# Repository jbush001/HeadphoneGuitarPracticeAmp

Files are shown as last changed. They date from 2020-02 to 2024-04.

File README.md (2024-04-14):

I was looking for a headphone guitar amp with the following features:

- Integrated guitar plug: Doesn't require an extra cable or have a box
  flopping around.
- Rechargeable battery
- Flexible set of basic effects with decent quality: distortion, reverb,
  amp simulation, etc.
- Built-in metronome

Although there are commercially available headphone amps that support a few of
these, surprisingly, none supported all of them, so I decided to build my own.
The heart of this is an ARM microcontroller, which processes the audio signal
and applies digital effects. The hardware consists of a custom printed circuit
board in a 3D printed enclosure.

TBH, I kind of ran out of steam on this project. Pictures of the prototype I built
are in the Wiki: <https://github.com/jbush001/HeadphoneGuitarPracticeAmp/wiki/Prototype-Pictures>,
but I didn't end up bringing this up.



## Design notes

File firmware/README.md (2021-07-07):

Setting up software development environment:

* <https://www.amazon.com/Aideepen-ST-Link-Programming-Emulator-Downloader/dp/B01J7N3RE6>
* <https://www.amazon.com/DSD-TECH-SH-U09C2-Debugging-Programming/dp/B07TXVRQ7V>

## Macos

Install ARM toolchain:

    brew tap ArmMbed/homebrew-formulae
    brew install arm-none-eabi-gcc

## Linux

    sudo apt-get install gcc-arm-none-eabi binutils-arm-none-eabi

This requires at least version 1.6.1 of the st-link tools for STM32G4 support. This version
is not in Homebrew (at least), so they need to be built manually following instructions here:
<https://github.com/stlink-org/stlink/blob/develop/doc/compiling.md#macOS>

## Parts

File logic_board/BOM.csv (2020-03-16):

Manufacturer Part Number | Manufacturer | Digi-Key Part Number | Quantity | Unit Price | Description
C0805C106K8PACTU | KEMET | 399-4925-1-ND | 3 | 0.16000 | CAP CER 10UF 10V X5R 0805
 |  |  | 12 | 0.01800 | CAP CER 0.1UF 16V Y5V 0603
EEE-1VA220SP | Panasonic Electronic Components | PCE3952CT-ND | 2 | 0.35000 | CAP ALUM 22UF 20% 35V SMD
WP710A10LSRD | Kingbright | 754-1590-ND | 2 | 0.50000 | LED RED DIFFUSED T-1 T/H
LTST-C191TBKT | Lite-On Inc. | 160-1647-1-ND | 1 | 0.50000 | LED BLUE CLEAR CHIP SMD
SJ2-35953A-SMT-TR | CUI Devices | CP-SJ2-35953A-SMT-CT-ND | 1 | 1.41000 | AUDIO JACK, 3.5 MM, RT, 3 CONDUC
USB4085-GF-A | GCT | 2073-USB4085-GF-ATR-ND | 1 | 1.75000 | CONN RCPT USB2.0 TYPEC 16POS
B2B-PH-SM4-TB(LF)(SN) | JST Sales America Inc. | 455-1734-1-ND | 1 | 0.55000 | CONN HEADER SMD 2POS 2MM
,",",2" | 0.45000 | RES SMD 5.1K OHM 0.1% 1/16W 0603
PTN0805E5002BST1 | Vishay Thin Film | 764-1535-1-ND | 1 | 0.74000 | RES 50K OHM 0.1% 1/5W 0805
 |  |  | 1 | 0.10000 | RES SMD 100K OHM 1% 1/16W 0603
 |  |  | 2 | 0.10000 | RES SMD 47K OHM 1% 1/16W 0603
 |  |  | 1 | 0.10000 | RES SMD 1K OHM 1% 1/16W 0603
 |  |  | 1 | 0.10000 | RES SMD 2K OHM 1% 1/16W 0603
 |  |  | 3 | 0.43000 | RES SMD 1.5K OHM 0.1% 1/16W 0603
TL3315NF160Q | E-Switch | EG4621CT-ND | 4 | 0.18000 | SWITCH TACTILE SPST-NO 0.05A 15V
JS102011SAQN | C&K | 401-1999-1-ND | 1 | 0.56000 | SWITCH SLIDE SPDT 300MA 6V
STM32G473CET6 | STMicroelectronics | 497-STM32G473CET6-ND | 1 | 6.29000 | MAINSTREAM ARM CORTEX-M4 CORE WI
OPA340NA/3K | Texas Instruments | 296-26275-1-ND | 1 | 2.54000 | IC OPAMP GP 1 CIRCUIT SOT23-5
WM8731SEDS/V | Cirrus Logic Inc. | 598-2460-ND | 1 | 3.92000 | IC CODEC PORT INTERNET 28SSOP
SPX3819M5-L-3-3/TR | MaxLinear, Inc. | 1016-1873-1-ND | 1 | 0.51000 | IC REG LINEAR 3.3V 500MA SOT23-5
BQ24090DGQT | Texas Instruments | 296-25863-1-ND | 1 | 1.48000 | IC BATT CHRGR LI-ION 10MSOP
AWSCR-8.00CPLB-C30-T4 | Abracon LLC | 535-15118-1-ND | 1 | 0.50000 | CERAMIC RES 8.0000MHZ 30PF SMD
AWSCR-12.00CV-T | Abracon LLC | 535-10007-1-ND | 1 | 0.40000 | CERAMIC RES 12.0000MHZ 22PF SMD
2750 | Adafruit Industries LLC | 1528-1858-ND | 1 | 6.95000 | BATTERY LITHIUM 3.7V 350MAH
2P1216 | Switchcraft Inc. | SC2075-ND | 1 | 4.06000 | CONN PLUG MONO 6.35MM 2COND
 |  |  | 1 | 0.47000 | CAP CER 10UF 10V X5R 0603
EEE-1AA221XP | Panasonic Electronic Components | PCE3871CT-ND | 2 | 0.47000 | CAP ALUM 220UF 20% 10V SMD

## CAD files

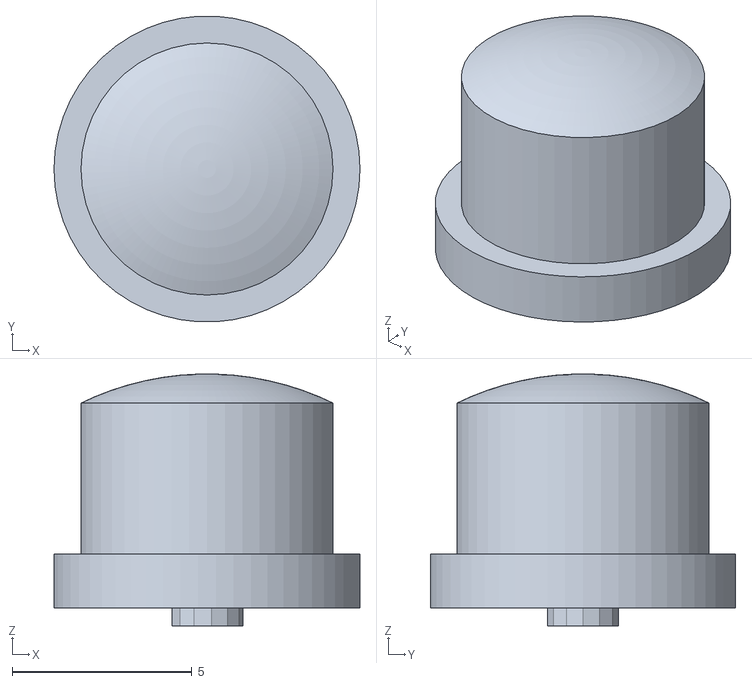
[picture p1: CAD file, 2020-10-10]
enclosure/button.stl
8.50 x 8.49 x 7.00

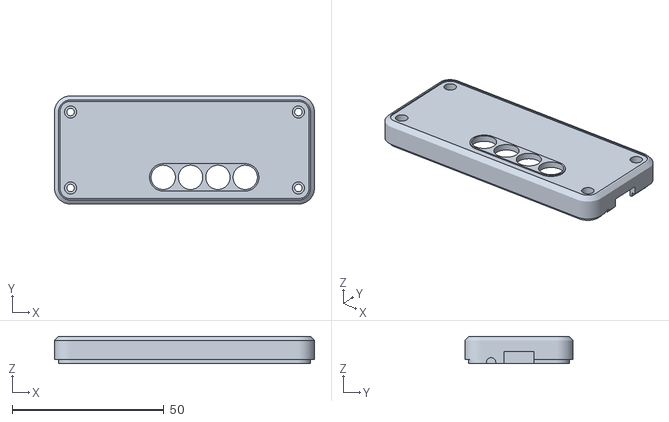
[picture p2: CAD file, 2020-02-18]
enclosure/top_enclosure.stl
85.6 x 35.6 x 9.00

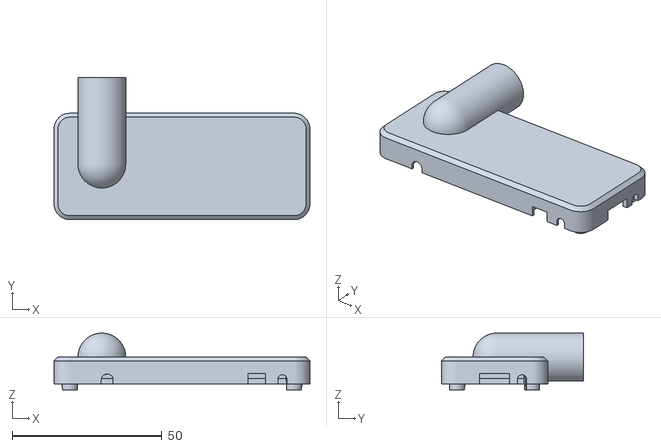
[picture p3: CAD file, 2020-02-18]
enclosure/bottom_enclosure.stl
85.6 x 47.6 x 19.0

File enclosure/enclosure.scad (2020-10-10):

//
// Print Settings (tested with Cura Slicer, Creality Ender 3)
//   Infill Density: 20%
//   Support Placement: Everywhere
//   Support Density: 20%
//   Layer Height: 0.2mm
// Both shells are printed with the open side pointed towards the print bed.
//

epsilon = 0.001; // Small offset used to avoid z-fighting
relief = 0.5; // Gap between interfacing parts to avoid sticking. Specific to printing process.
wall = 2; // Thickness of walls
pcb_thickness = 1.5; // Oshpark 4 layer board (actually 1.46)
$fs = 0.5;
$fa = 0.5;

pcb_xy_gap = 0.8; // horizontal gap between PCB and inside enclosure wall, on all sides.
enclosure_radius = 2.5 + wall + pcb_xy_gap;
pcb_width = 80;
pcb_height = 30;
pcb_screw_inset = 2.5; // center of screw from edge of PCB
pcb_z_offset = 3 + wall; // From top surface
lip_height = 1.8;
plug_cylinder_or = 16 / 2;
plug_cylinder_len = 37;
plug_opening_id = 10;
plug_x_offset = 8;
boss_od = pcb_screw_inset * 2;
top_boss_id = 2.5;   // For an M2.3 screw, should be larger
bottom_boss_id = 2.2;   // Also for M2.3 screw, we want it to self thread into this.
counterbore_id = 4.0; // Head of screw is 3.56mm
top_shell_depth = 9;
bottom_shell_depth = 9;
shell_width = pcb_width + pcb_xy_gap * 2 + wall * 2;
shell_height = pcb_height + pcb_xy_gap * 2 + wall * 2;
headphone_jack_radius = 3.175 / 2;
led_radius = 2.5; // 5mm

module shell(width, height, depth, radius) {
    hull() {
        chamfer = radius / 4;

        x1 = radius;
        y1 = radius;
        x2 = width - radius;
        y2 = height - radius;

        translate([x1, y1, 0]) cylinder(r=radius, h=depth - chamfer);
        translate([x2, y1, 0]) cylinder(r=radius, h=depth - chamfer);
        translate([x1, y2, 0]) cylinder(r=radius, h=depth - chamfer);
        translate([x2, y2, 0]) cylinder(r=radius, h=depth - chamfer);

        translate([x1, y1, 0]) cylinder(r=radius - chamfer, h=depth);
        translate([x2, y1, 0]) cylinder(r=radius - chamfer, h=depth);
        translate([x1, y2, 0]) cylinder(r=radius - chamfer, h=depth);
        translate([x2, y2, 0]) cylinder(r=radius - chamfer, h=depth);
    }
}

// Radius all vertical surfaces, but not top and bottom
module rounded_rect(width, height, depth, radius) {
    hull() {
        translate([radius, radius, 0]) cylinder(r=radius, h=depth);
        translate([width - radius, radius, 0]) cylinder(r=radius, h=depth);
        translate([width - radius, height - radius, 0]) cylinder(r=radius, h=depth);
        translate([radius, height - radius, 0]) cylinder(r=radius, h=depth);
    }
}

// Cylinder with a ball end
module rounded_cylinder(height, radius) {
    translate([radius, radius, 0]) cylinder(h=height - radius, r=radius);
    translate([radius, radius, height - radius]) sphere(radius);
}

module bottom_shell() {
    difference() {
        union() {
            // Outer shell
            translate([0, 0, 0]) shell(shell_width, shell_height, bottom_shell_depth, enclosure_radius);

            // Plug holder
            rotate([90, 0, 0]) translate([plug_x_offset, bottom_shell_depth - plug_cylinder_or, -shell_height - 12]) {
                rounded_cylinder(plug_cylinder_len, plug_cylinder_or);
            }
        }

        union() {
            translate([0, 0, -20]) cube([shell_width, shell_height, 20]);
            translate([wall, wall, -wall]) shell(shell_width - wall * 2, shell_height - wall * 2,
                bottom_shell_depth, enclosure_radius - wall);

            // lip (outer)
            translate([wall / 2 - relief / 2, wall / 2 - relief / 2, -epsilon])
                rounded_rect(shell_width - (wall / 2) * 2 - relief, shell_height - (wall / 2 / 2) * 2 - relief,
                    lip_height, enclosure_radius - (wall - wall / 2 - relief));

            // Inside of plug holder
            rotate([90, 0, 0]) translate([plug_x_offset, bottom_shell_depth - plug_cylinder_or, -shell_height - 12 + wall]) {
                translate([wall, wall, -epsilon]) rounded_cylinder(plug_cylinder_len - wall * 2 + epsilon, plug_cylinder_or - wall);
                translate([plug_cylinder_or, plug_cylinder_or, -3]) cylinder(d=plug_opening_id, h=6); // Opening
            }
        }
    }

}

module top_shell() {
    INSET = wall / 2;

    difference() {
        union() {
            difference() {
                shell(shell_width, shell_height, top_shell_depth, enclosure_radius);
                translate([-epsilon, -epsilon, -10]) cube([shell_width + epsilon * 2, shell_height + epsilon * 2,
                    10 + lip_height - relief]);
            }

            // Lip (inner)
            translate([wall / 2 + relief / 2, INSET + relief / 2, -epsilon]) rounded_rect(
                shell_width - wall - relief,
                shell_height - wall - relief,
                INSET * 2, enclosure_radius - (wall - INSET));
        }

        // Cavity
        translate([wall, wall, -wall]) shell(shell_width - wall * 2, shell_height - wall * 2,
            top_shell_depth, enclosure_radius - wall);
    }
}

module make_side_hole(diameter, isbottom) {
    cylinder(d=diameter, h=4);
    if (isbottom)
        translate([-diameter / 2, 0, 0]) cube([diameter, diameter + 1, 4]);
    else
        translate([-diameter / 2, -diameter, 0]) cube([diameter, diameter, 4]);
}


// This is from the origin of the top surface of the PCB, with positive
// extending away from the bottom.
// The isbottom flag cuts the lip away in the correct direction.
module openings(isbottom) {
    // USB port. This extends 3.2mm from the PCB surface it is soldered to and is
    // about 9.18mm wide.
    usb_port_width = 10;
    usb_port_height = 4;
    translate([pcb_width - 1, (pcb_height - usb_port_width) / 2, 0])
        cube([4, usb_port_width, usb_port_height + pcb_thickness]);

    // Charging LED
    translate([pcb_width - 1, 24.19, pcb_thickness + led_od / 2 + 0.5]) rotate([90, 180, 90])
        make_side_hole(led_od, isbottom);

    // Power LED
    led_od = 3.1;
    translate([73.56836, -3, pcb_thickness + led_od / 2 + 0.5]) rotate([-90, 0, 0]) make_side_hole(led_od,  isbottom);

    // Power switch
    // Center x is 70mm from origin
    // 2mm travel, switch is 1.5mm wide.
    translate([65 - 3, -3, 0]) cube([6, 5, 4 + pcb_thickness]);

    // Audio jack
    jack_id = 4;
    translate([15, -3, pcb_thickness + 1.85]) rotate([-90, 0, 0]) make_side_hole(jack_id, isbottom);

    // Front buttons
    for (i = [0:3])
        translate([33 + i * 9, 24, 0]) rotate([0, -180, 0]) cylinder(d=7 + relief * 2, h=7);
}

module bottom_enclosure() {
    boss_length = top_shell_depth + bottom_shell_depth - pcb_z_offset - pcb_thickness - relief; // offset from bottom surface
    boss_top = bottom_shell_depth - boss_length;
    xy1 = pcb_screw_inset + wall + pcb_xy_gap;
    x2 = xy1 + pcb_width - pcb_screw_inset * 2;
    y2 = xy1 + pcb_height - pcb_screw_inset * 2;

    difference() {
        union() {
            bottom_shell();

            translate([xy1, xy1, boss_top]) cylinder(d1=boss_od, d2=boss_od + 1, h=boss_length);
            translate([x2, xy1, boss_top]) cylinder(d1=boss_od, d2=boss_od + 1, h=boss_length);
            translate([xy1, y2, boss_top]) cylinder(d1=boss_od, d2=boss_od + 1, h=boss_length);
            translate([x2, y2, boss_top]) cylinder(d1=boss_od, d2=boss_od + 1, h=boss_length);
        }

        union() {
            // Screw holes to attach to top.
            translate([xy1, xy1, boss_top - epsilon]) cylinder(d=bottom_boss_id, h=boss_length - wall);
            translate([x2, xy1, boss_top - epsilon]) cylinder(d=bottom_boss_id, h=boss_length - wall);
            translate([xy1, y2, boss_top - epsilon]) cylinder(d=bottom_boss_id, h=boss_length - wall);
            translate([x2, y2, boss_top - epsilon]) cylinder(d=bottom_boss_id, h=boss_length - wall);
            translate([wall + pcb_xy_gap, wall + pcb_xy_gap, boss_top]) openings(true);
        }
    }
}

module top_enclosure() {
    pcb_boss_bottom = top_shell_depth - pcb_z_offset;

    xy1 = pcb_screw_inset + wall + pcb_xy_gap;
    x2 = xy1 + pcb_width - pcb_screw_inset * 2;
    y2 = xy1 + pcb_height - pcb_screw_inset * 2;

    difference() {
        union() {
            top_shell();

            // Bosses to attach to bottom
            translate([xy1, xy1, pcb_boss_bottom]) cylinder(d1=boss_od, d2=boss_od + 1, h=pcb_z_offset);
            translate([x2, xy1, pcb_boss_bottom]) cylinder(d1=boss_od, d2=boss_od + 1, h=pcb_z_offset);
            translate([xy1, y2, pcb_boss_bottom]) cylinder(d1=boss_od, d2=boss_od + 1, h=pcb_z_offset);
            translate([x2, y2, pcb_boss_bottom]) cylinder(d1=boss_od, d2=boss_od + 1, h=pcb_z_offset);
        }
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

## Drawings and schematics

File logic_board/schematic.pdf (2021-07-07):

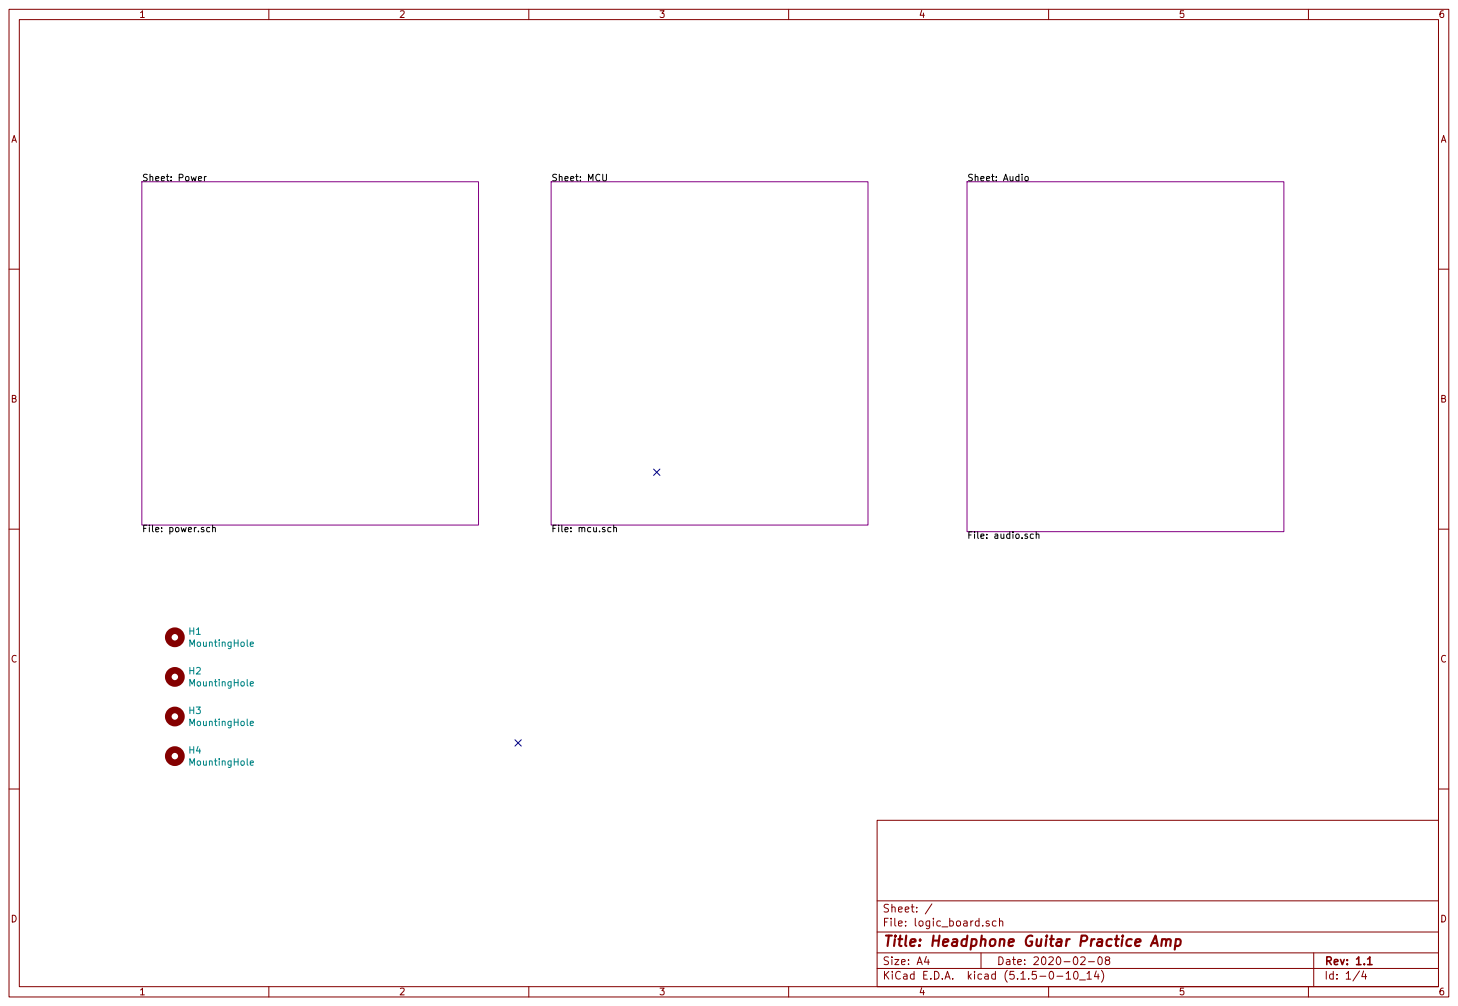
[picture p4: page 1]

File: logic_board.sch Sheet: /
Id: 1/4 Title: Headphone Guitar Practice Amp

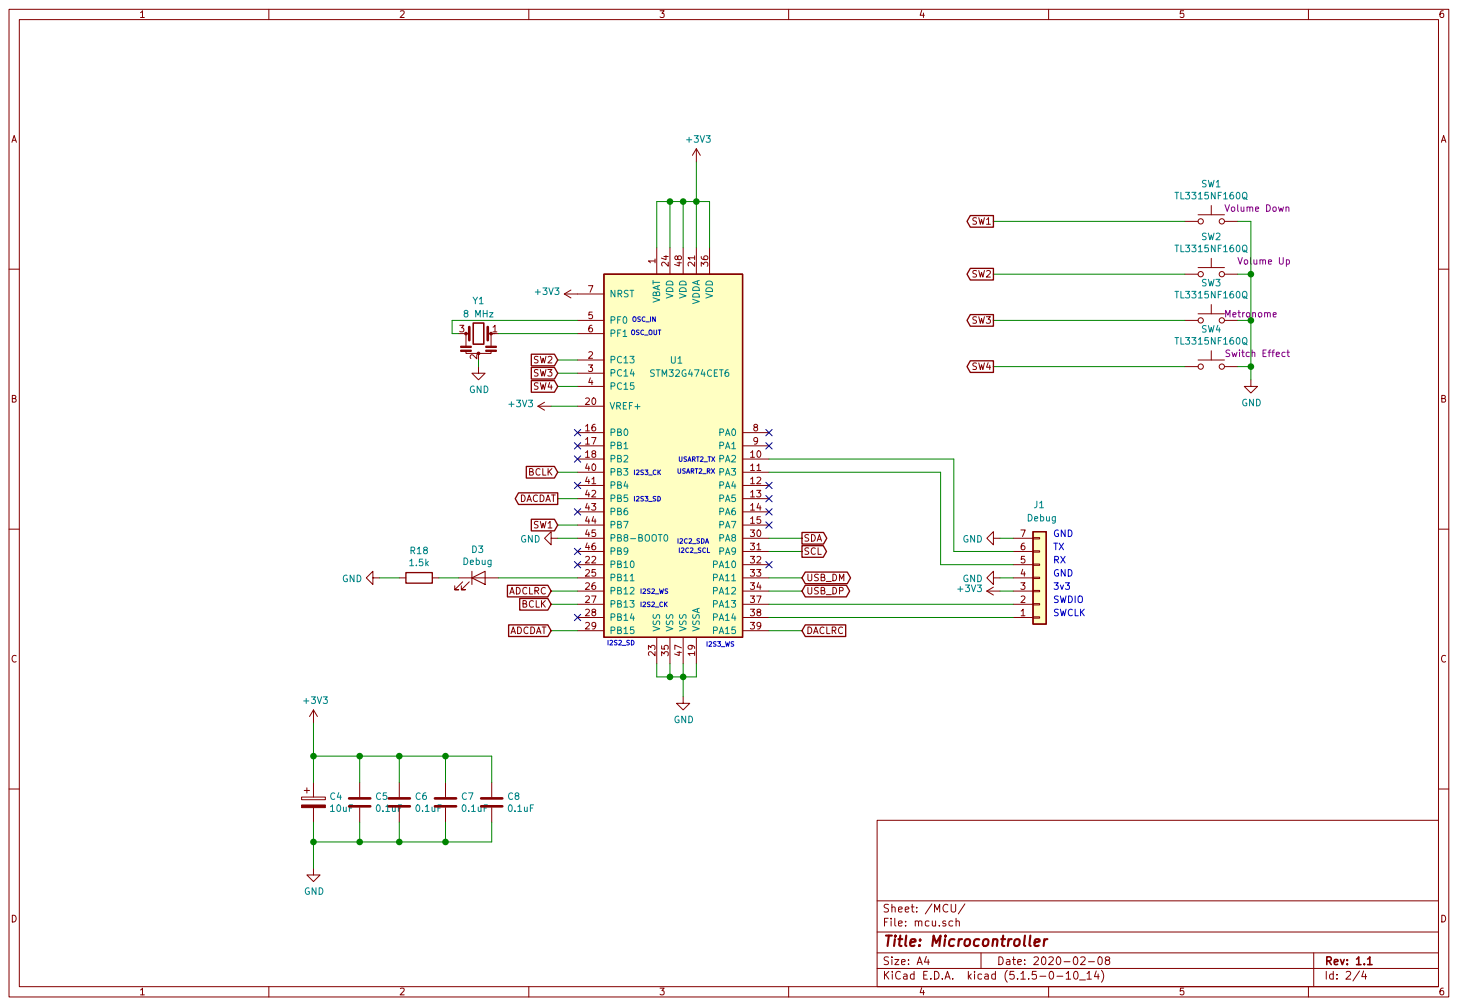
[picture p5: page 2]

1 PA2 10 PA3 11 PA4 12 PA5 13 PA6 14 PA7 15 PB0 16 PB1 17 PB2 18 VSSA 19 PC13 2 VREF+ 20 VDDA 21 PB10 22 VSS 23 VDD 24 PB11 25 PB12 26 PB13 27 PB14 28 PB15 29 PC14 3 PA8 30 PA9 31 PA10 32 PA11 33 PA12 34 VSS 35 VDD 36 PA13 37 PA14 38 PA15 39 PC15 4 PB3 40 PB4 41 PB5 42 PB6 43 PB7 44 PB8-BOOT0 45 PB9 46 VSS 47 VDD 48 PF0 5 PF1 6 NRST 7 PA0 8 PA1 9 U1 STM32G474CET6 C4

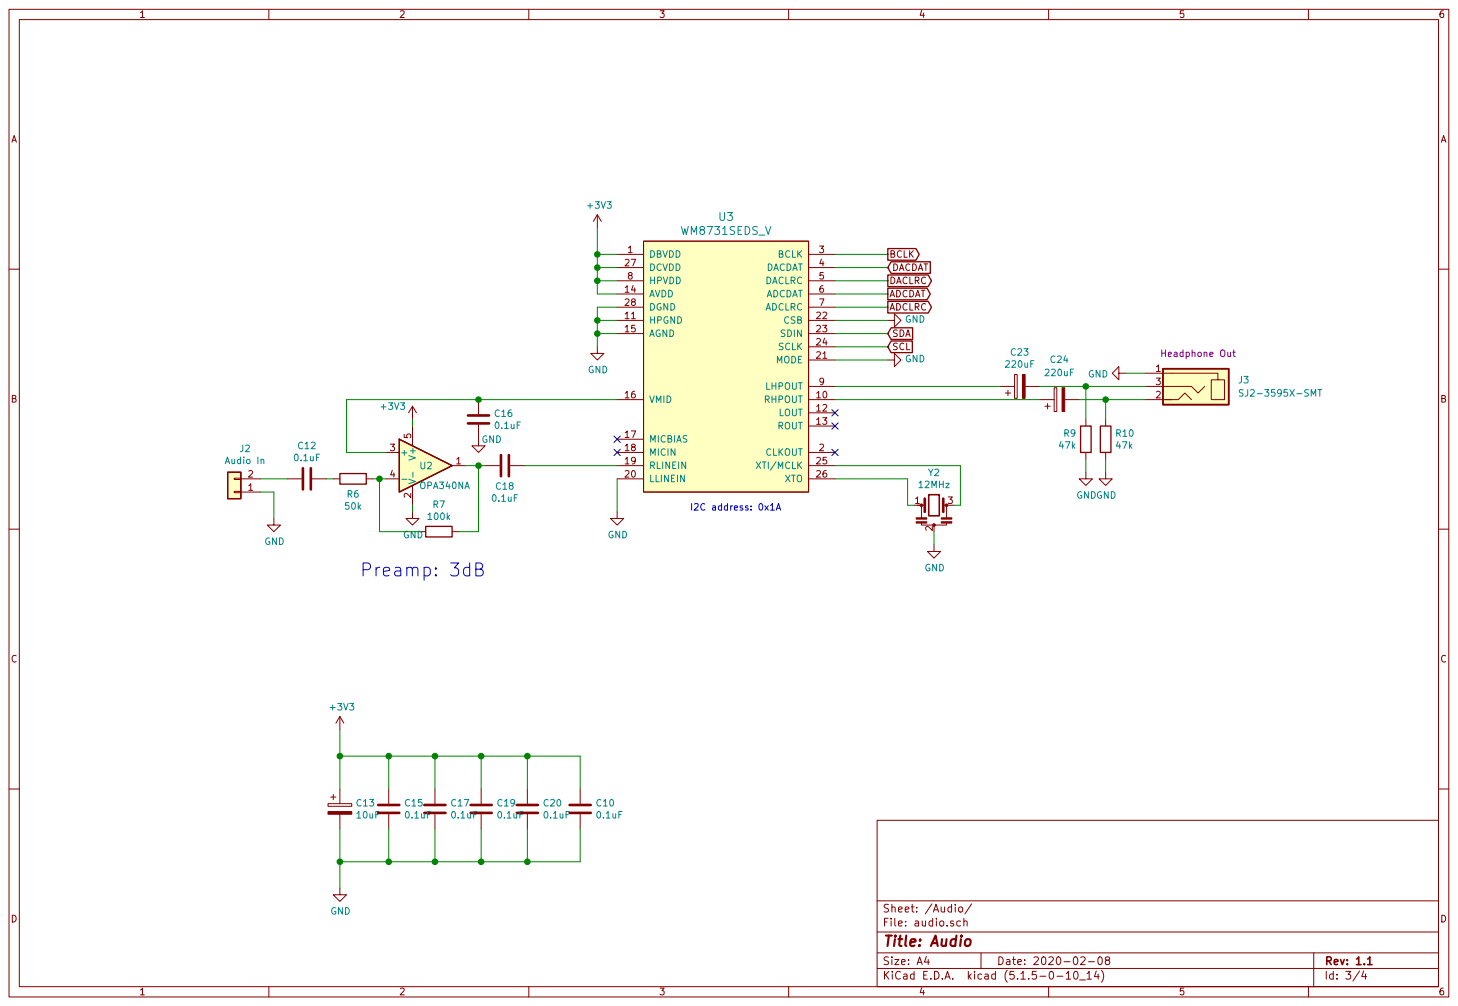
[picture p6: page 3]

File: audio.sch Sheet: /Audio/
Id: 3/4 Title: Audio

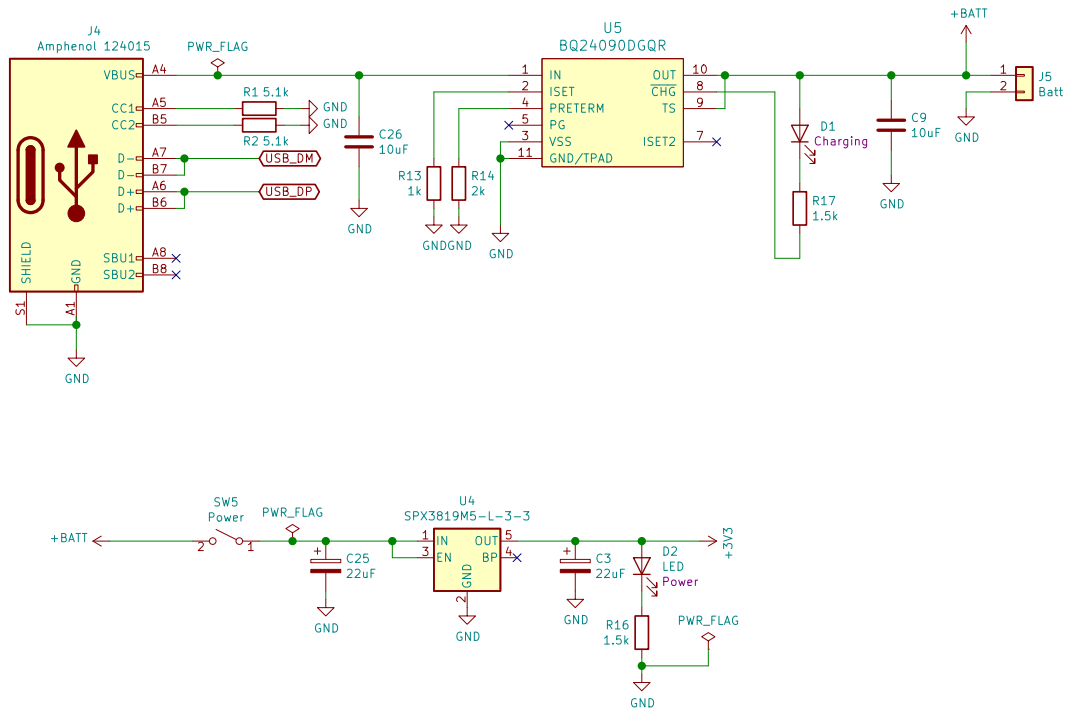
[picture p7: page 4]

2 EN 3 BP 4 OUT 5 U4 PWR_FLAG SPX3819M5-L-3-3 GND GND

File: power.sch Sheet: /Power/
Id: 4/4 Title: Power

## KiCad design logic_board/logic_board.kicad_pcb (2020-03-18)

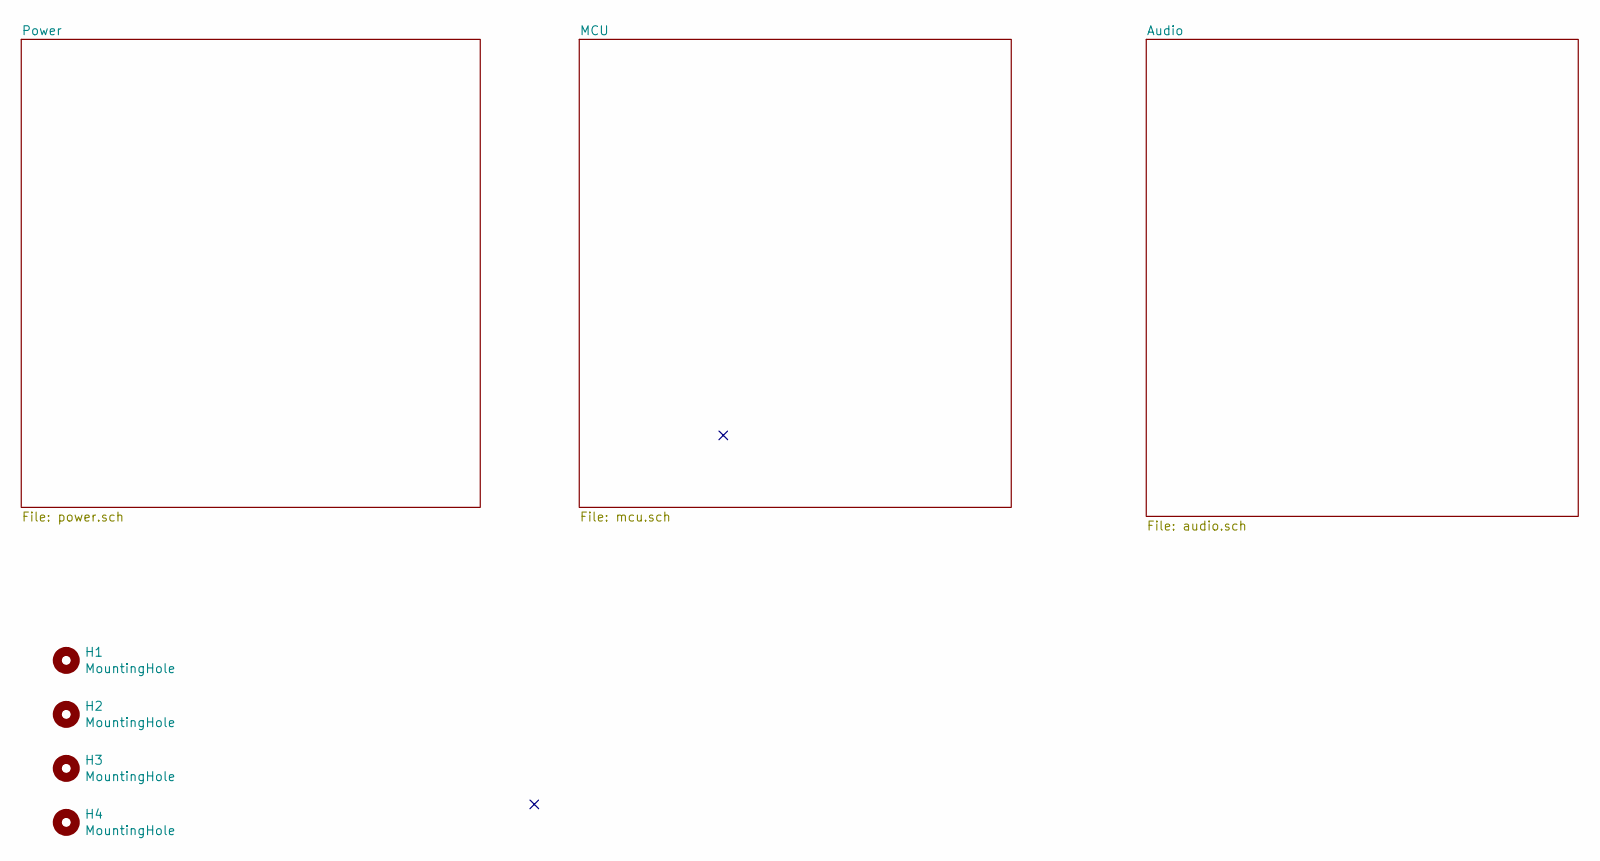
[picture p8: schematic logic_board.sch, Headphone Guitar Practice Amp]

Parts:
H1, H2, H3, H4: MountingHole; MountingHole_2.5mm

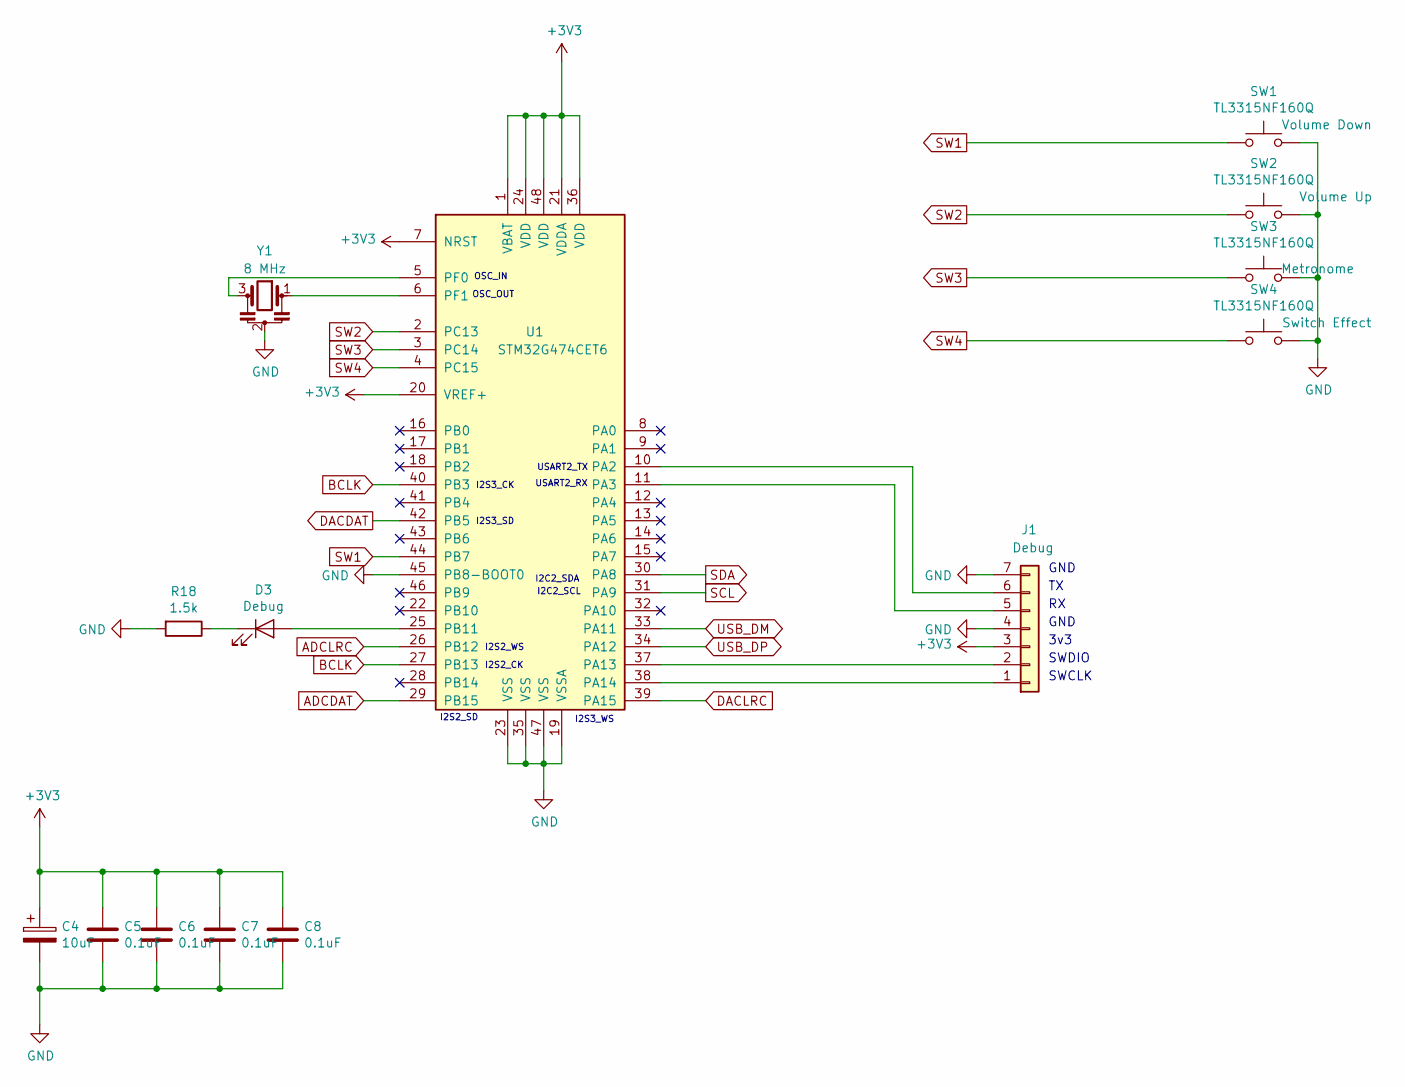
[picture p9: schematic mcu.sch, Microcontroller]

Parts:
C4: 10uF; C_0805_2012Metric_Pad1.15x1.40mm_HandSolder
C5, C6, C7, C8: 0.1uF; C_0603_1608Metric_Pad1.05x0.95mm_HandSolder
D3: Debug; LED_0603_1608Metric_Pad1.05x0.95mm_HandSolder
J1: Debug; PinHeader_1x07_P2.54mm_Vertical
R18: 1.5k; R_0603_1608Metric_Pad1.05x0.95mm_HandSolder
SW1, SW2, SW3, SW4: TL3315NF160Q; TL3315NF160Q_Tactile_Switch
U1: STM32G474CET6; LQFP-48_7x7mm_P0.5mm
Y1: 8 MHz; AWSCR-8.00CPLB-C30-T4

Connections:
+3V3: C4.1, C5.1, C6.1, C7.1, C8.1, J1.3, U1.1 (VBAT), U1.7 (NRST), U1.20 (VREF+), U1.21 (VDDA), U1.24 (VDD), U1.36 (VDD), U1.48 (VDD); also elsewhere on the board
ADCDAT: U1.29 (PB15); also elsewhere on the board
ADCLRC: U1.26 (PB12); also elsewhere on the board
BCLK: U1.27 (PB13), U1.40 (PB3); also elsewhere on the board
DACDAT: U1.42 (PB5); also elsewhere on the board
DACLRC: U1.39 (PA15); also elsewhere on the board
GND: C4.2, C5.2, C6.2, C7.2, C8.2, J1.4, J1.7, R18.2, SW1.2, SW2.2, SW3.2, SW4.2, U1.19 (VSSA), U1.23 (VSS), U1.35 (VSS), U1.45 (PB8-BOOT0), U1.47 (VSS), Y1.2; also elsewhere on the board
unnamed: D3.1 (K), R18.1
unnamed: D3.2 (A), U1.25 (PB11)
unnamed: J1.1, U1.38 (PA14)
unnamed: J1.2, U1.37 (PA13)
unnamed: J1.5, U1.11 (PA3)
unnamed: J1.6, U1.10 (PA2)
unnamed: U1.5 (PF0), Y1.3
unnamed: U1.6 (PF1), Y1.1
SCL: U1.31 (PA9); also elsewhere on the board
SDA: U1.30 (PA8); also elsewhere on the board
SW1: SW1.1, U1.44 (PB7)
SW2: SW2.1, U1.2 (PC13)
SW3: SW3.1, U1.3 (PC14)
SW4: SW4.1, U1.4 (PC15)
USB_DM: U1.33 (PA11); also elsewhere on the board
USB_DP: U1.34 (PA12); also elsewhere on the board

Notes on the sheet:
SWDIO
SWCLK
3v3
GND
I2S3_WS
I2S2_SD
I2S2_CK
I2S2_WS
I2S3_SD
I2S3_CK
USART2_TX
USART2_RX
I2C2_SDA
I2C2_SCL
OSC_IN
OSC_OUT

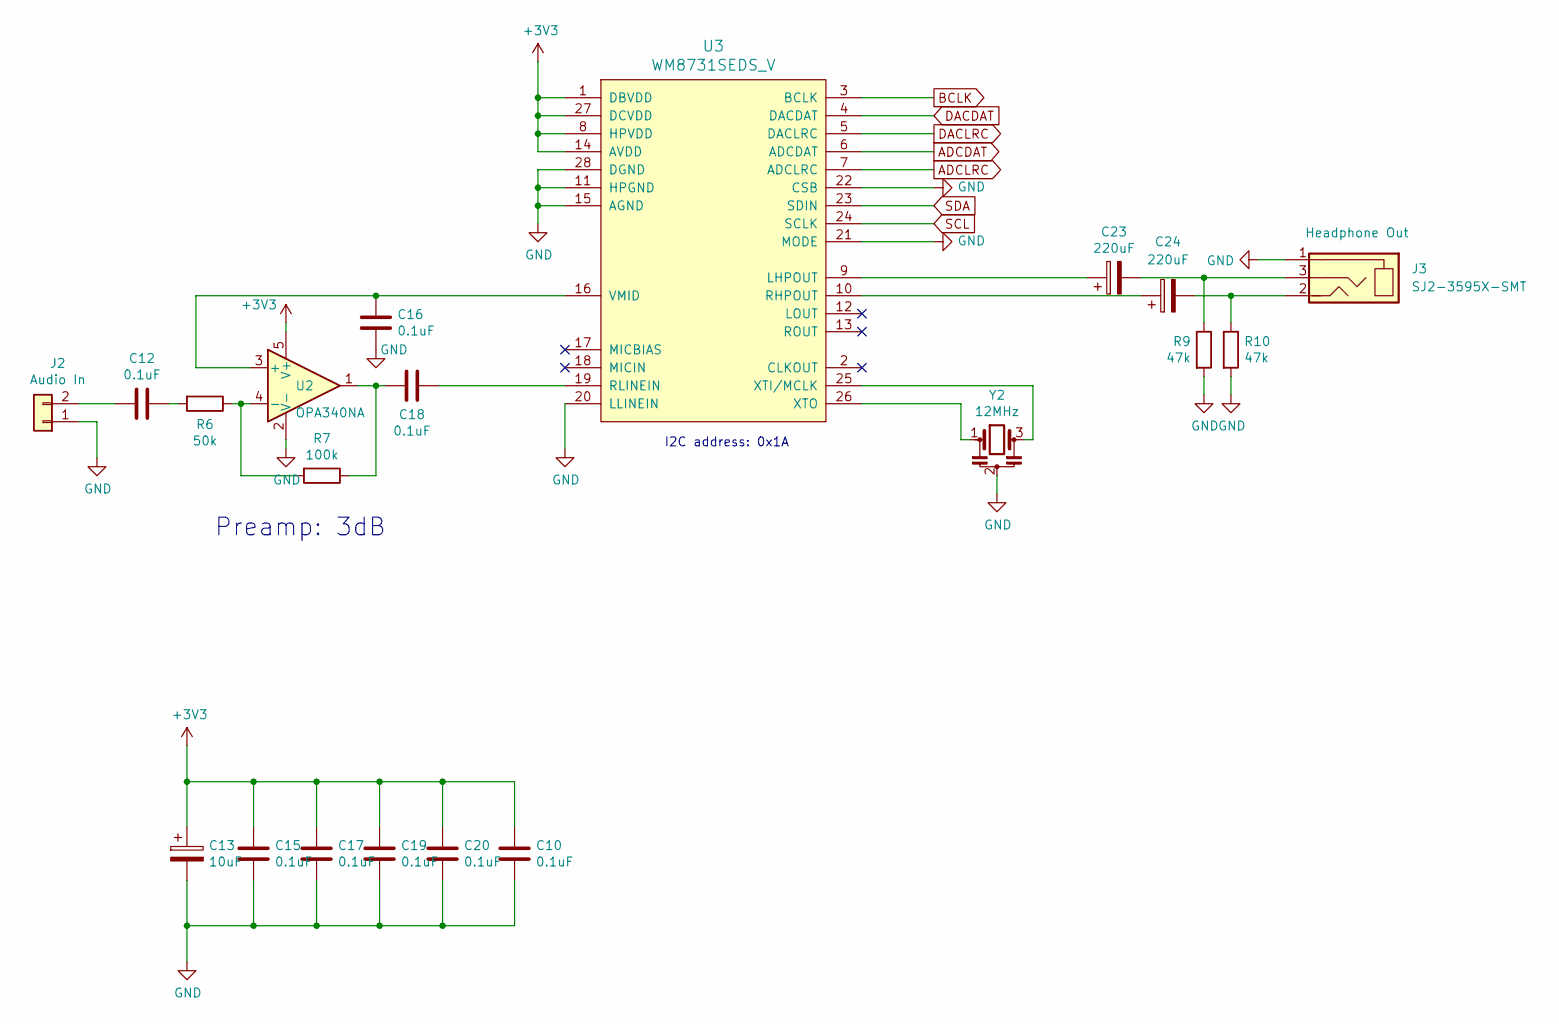
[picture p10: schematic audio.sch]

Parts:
C10, C12, C15, C16, C17, C18, C19, C20: 0.1uF; C_0603_1608Metric_Pad1.05x0.95mm_HandSolder
C13: 10uF; C_0805_2012Metric_Pad1.15x1.40mm_HandSolder
C23, C24: 220uF; C_1206_3216Metric_Pad1.42x1.75mm_HandSolder
J2: Audio In; Solder Pads 2x1
J3: SJ2-3595X-SMT; SJ2-3595X-SMT_3.5MM_JACK
R6: 50k; R_0805_2012Metric_Pad1.15x1.40mm_HandSolder
R7: 100k; R_0603_1608Metric_Pad1.05x0.95mm_HandSolder
R9, R10: 47k; R_0603_1608Metric_Pad1.05x0.95mm_HandSolder
U2: OPA340NA; SOT-23-5_HandSoldering
U3: WM8731SEDS_V; SSOP-28_5.3x10.2mm_P0.65mm
Y2: 12MHz; AWSCR-12.00CV-T

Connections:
+3V3: C10.1, C13.1, C15.1, C17.1, C19.1, C20.1, U2.5 (V+), U3.1 (DBVDD), U3.8 (HPVDD), U3.14 (AVDD), U3.27 (DCVDD); also elsewhere on the board
ADCDAT: U3.6 (ADCDAT); also elsewhere on the board
ADCLRC: U3.7 (ADCLRC); also elsewhere on the board
BCLK: U3.3 (BCLK); also elsewhere on the board
DACDAT: U3.4 (DACDAT); also elsewhere on the board
DACLRC: U3.5 (DACLRC); also elsewhere on the board
GND: C10.2, C13.2, C15.2, C16.2, C17.2, C19.2, C20.2, J2.1, J3.1, R9.2, R10.2, U2.2 (V-), U3.11 (HPGND), U3.15 (AGND), U3.20 (LLINEIN), U3.21 (MODE), U3.22 (CSB), U3.28 (DGND), Y2.2; also elsewhere on the board
unnamed: C12.1, R6.2
unnamed: C12.2, J2.2
unnamed: C16.1, U2.3 (+), U3.16 (VMID)
unnamed: C18.1, R7.1, U2.1
unnamed: C18.2, U3.19 (RLINEIN)
unnamed: C23.1, U3.9 (LHPOUT)
unnamed: C23.2, J3.3, R9.1
unnamed: C24.1, U3.10 (RHPOUT)
unnamed: C24.2, J3.2, R10.1
unnamed: R6.1, R7.2, U2.4 (-)
unnamed: U3.25 (XTI/MCLK), Y2.3
unnamed: U3.26 (XTO), Y2.1
SCL: U3.24 (SCLK); also elsewhere on the board
SDA: U3.23 (SDIN); also elsewhere on the board

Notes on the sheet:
Preamp: 3dB
I2C address: 0x1A

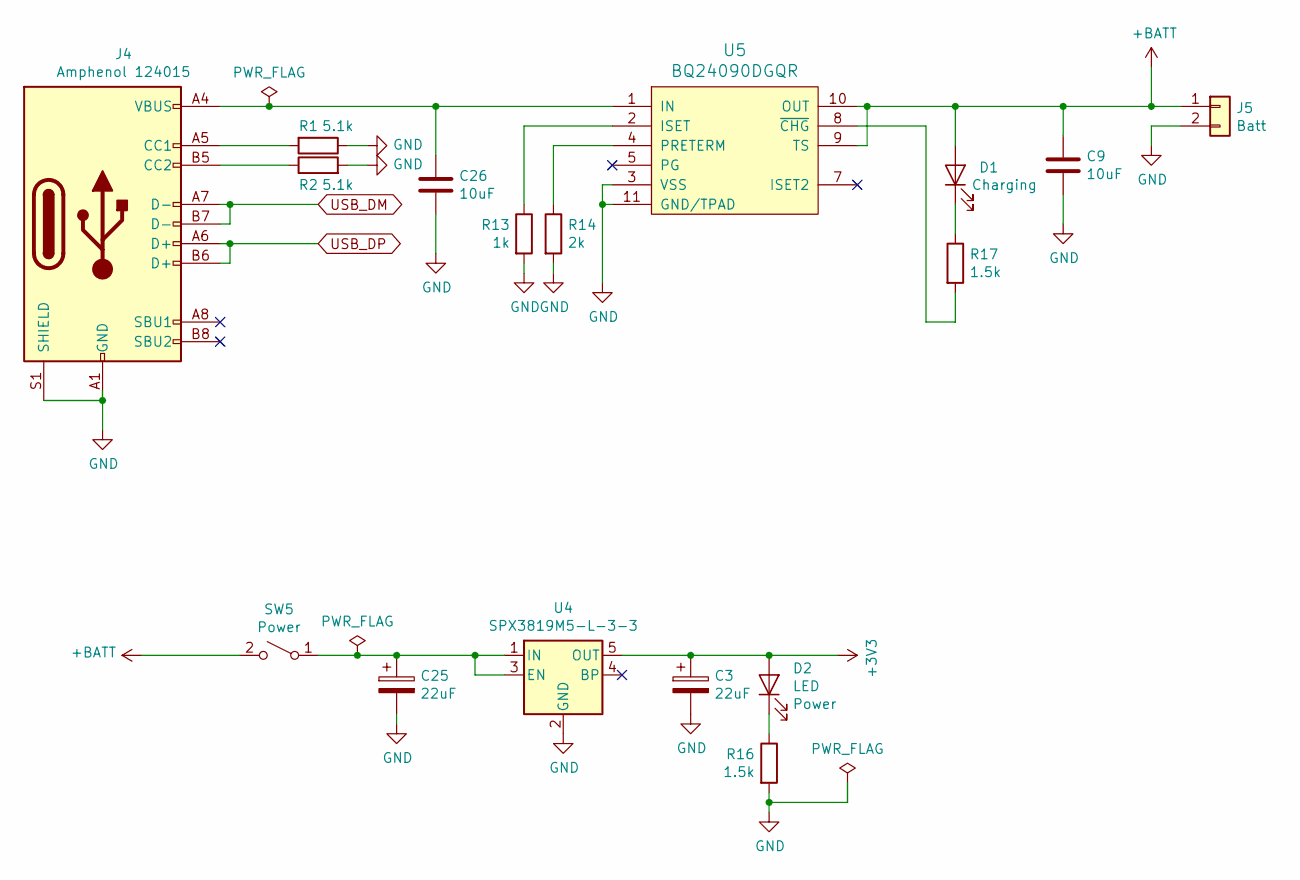
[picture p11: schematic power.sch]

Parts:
C3, C25: 22uF; CP_Elec_6.3x4.5
C9: 10uF; C_0603_1608Metric_Pad1.05x0.95mm_HandSolder
C26: 10uF; C_0805_2012Metric_Pad1.15x1.40mm_HandSolder
D1, D2: LED; LED_D3.0mm_Horizontal_O1.27mm_Z2.0mm
J4: Amphenol 124015; USB_C_Receptacle_GCT_USB4085
J5: Batt; JST PH HEADER SMD 2POS 2MM
R1, R2: 5.1k; R_0603_1608Metric_Pad1.05x0.95mm_HandSolder
R13: 1k; R_0603_1608Metric_Pad1.05x0.95mm_HandSolder
R14: 2k; R_0603_1608Metric_Pad1.05x0.95mm_HandSolder
R16, R17: 1.5k; R_0603_1608Metric_Pad1.05x0.95mm_HandSolder
SW5: Power; JS102011SAQN
U4: SPX3819M5-L-3-3; SOT-23-5_HandSoldering
U5: BQ24090DGQR; MSOP-10-1EP_3x3mm_P0.5mm_EP1.68x1.88mm

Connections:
+3V3: C3.1, D2.2 (A), U4.5 (OUT); also elsewhere on the board
+BATT: C9.1, D1.2 (A), J5.1, SW5.2 (B), U5.9 (TS), U5.10 (OUT)
GND: C3.2, C9.2, C25.2, C26.2, J4.A1 (GND), J4.A12 (GND), J4.B1 (GND), J4.B12 (GND), J4.S1 (SHIELD), J5.2, R1.1, R2.2, R13.2, R14.2, R16.2, U4.2 (GND), U5.3 (VSS), U5.11 (GND/TPAD); also elsewhere on the board
unnamed: C25.1, SW5.1 (A), U4.1 (IN), U4.3 (EN)
unnamed: C26.1, J4.A4 (VBUS), J4.A9 (VBUS), J4.B4 (VBUS), J4.B9 (VBUS), U5.1 (IN)
unnamed: D1.1 (K), R17.1
unnamed: D2.1 (K), R16.1
unnamed: J4.A5 (CC1), R1.2
unnamed: J4.B5 (CC2), R2.1
unnamed: R13.1, U5.2 (ISET)
unnamed: R14.1, U5.4 (PRETERM)
unnamed: R17.2, U5.8 (~CHG)
USB_DM: J4.A7 (D-), J4.B7 (D-); also elsewhere on the board
USB_DP: J4.A6 (D+), J4.B6 (D+); also elsewhere on the board

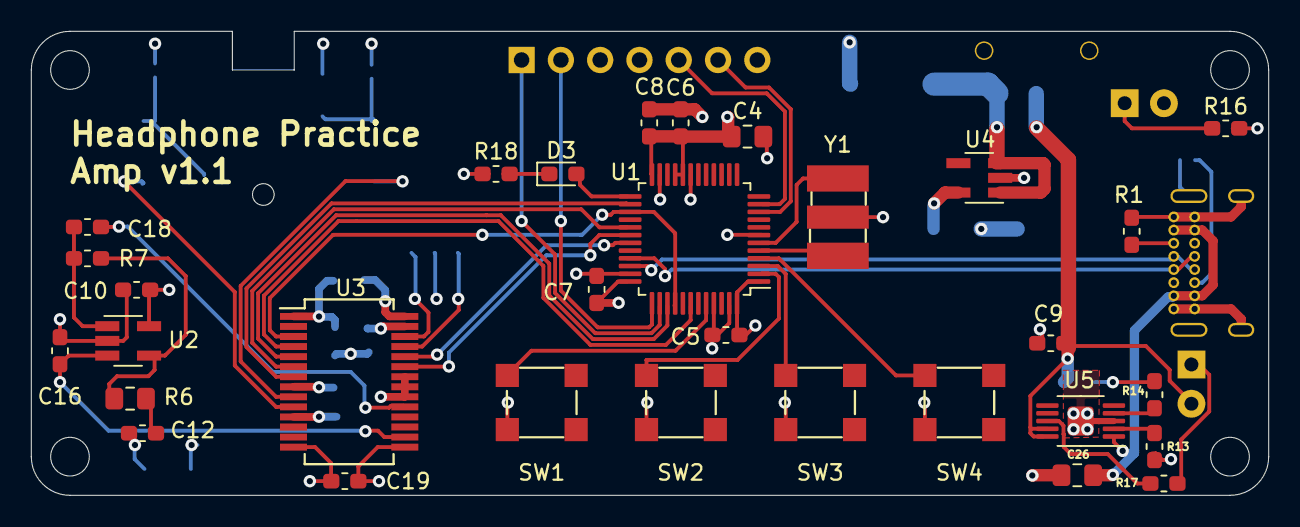
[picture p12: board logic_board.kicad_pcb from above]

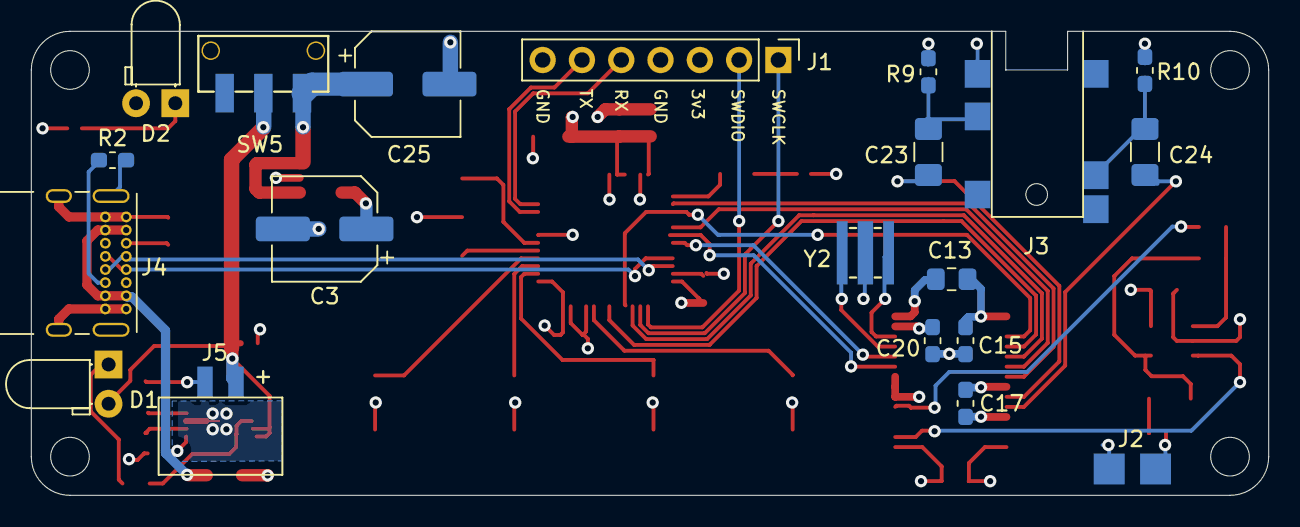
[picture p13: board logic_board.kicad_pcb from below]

Board: 4 copper layers, 80.0 x 30.0 mm, 55 parts (20 on the bottom side), 45 nets.

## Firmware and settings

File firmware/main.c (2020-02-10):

//
// Blink the LED attached to PB11
//

#define GPIO_REGB_BASE ((volatile unsigned int*) 0x48000400)
#define RCC_BASE ((volatile unsigned int*) 0X40021000)
#define GPIO_MODE 0
#define GPIO_OD 5
#define RCC_AHB2EN (0x4c / 4)

void main() {
    unsigned int counter = 0;

    // Enable clocks for GPIO blocks A, B, and C
    RCC_BASE[RCC_AHB2EN] = 0x7;

    // Make PB11 an output, everything else an input
    GPIO_REGB_BASE[GPIO_MODE] = 1 << 22;

    while (1) {
        GPIO_REGB_BASE[GPIO_OD] = (((counter >> 25) & 1) << 11);
        counter++;
    }
}

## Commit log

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2020-01-27 Some physical modifications to the board.
    - Round the corners of the board so it will fit in an enclosure that is less blocky.
    - Move the headphone jack to the back of the housing instead of the side. It could
    have gotten in the way in some configurations in the old position.
    - Realign the push buttons. I had hand placed them, so the distances between them were
    not completely even before. This will make it a bit easier to design the enclosure.
    - Add a BOM list with DigiKey links that I used to find component footprints.
    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
    [BOM.csv, logic_board.kicad_pcb]
2020-01-27 Add a JST battery connector
    The bare solder pads made me a bit nervous wrt the risk of shorting
    the battery. Uses 2mm JST connector, which seems to be a common battery
    connector.
    [BOM.csv, logic_board.kicad_pcb, power.sch]
2020-01-27 Add an edge notch for the headphone jack in its new placement,
    [logic_board.kicad_pcb]
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2020-01-28 Selected plug, added to enclosure model.
    Needed to modify enclosure to fit it.
    [BOM.csv, enclosure.scad, enclosure.stl]
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2020-01-30 Move in-pad vias off for small components, with a small trace.
    I realized for the 0402 components, there wasn't a lot of copper
    to solder onto, especially when both pads had vias in them.
    [logic_board.kicad_pcb]
2020-01-31 Re-layout for the third time
    In general, tried to make things a bit cleaner. Also:
    - Needed to add a capacitor on charger output.
    - Use a footprint with copper pad under charger for heat dissipation
    - Use through-hole LEDs, which are easier to bend 90 degrees to poke out
    the sides of the case.
    - I read about a trick: put all power supply bypass caps under the IC, which
    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
    [audio.sch, logic_board.kicad_pcb, power.sch]
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2020-02-01 Minor cleanup
    Move silk screened references so they don't get broken by vias.
    Move some components to give a little more breathing room.
    Fix some traces to be straighter.
    [logic_board.kicad_pcb]
2020-02-01 Update BOM
    Move power/charge LEDs back from edge so there's enough room. Use horizontal footprint.
    [BOM.csv, audio.sch, logic_board.kicad_pcb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]
2020-02-01 Pull BOOT0 pin down by default to boot from flash
    Also thickened some power traces to MPU.
    [enclosure.scad, logic_board.kicad_pcb, mcu.sch]
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2020-02-01 Fix a few formatting issues
    [BOM.csv]
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2020-02-01 Revert "Convert BOM to markdown"
    It looked much worse
    This reverts commit cd459a4850efa51b4b05e844350f85e8c8614377.
    [BOM.csv]
2020-02-02 Update enclosure
    The previous one wouldn't fit well in a strat with it's recessed jack.
    Also moved some footprints on the PCB to have more consistent spacing.
    [bottom_enclosure.stl, button.stl, enclosure.scad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]
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2020-02-02 A few tweaks based on test print
    - Add a Cura project for consistent settings
    - Make the upper countersink and screw holes larger, as they were a bit snug
    - Increase the relief size, as things did not fit well.
    - Remove the taper on the plug (NFC, as it was already parameterized this way)
    - Buttons were too short; they were flush with the top when inserted. Add a few mm.
    [cura_project.3mf, enclosure.scad]
2020-02-02 A few other enclosure improvements: - Use a chamfer instead of radius on the top and bottom edges. Whichever ones are parallel to the bed will always end up looking like chamfers anyway. - Make the p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
    [enclosure.scad, logic_board.kicad_pcb]
2020-02-02 A few other enclosure fixes
    - Needed to notch lip on top enclosure around holes
    - Due to making lip smaller, needed to increase height parameters
    for top and bottom to maintain total height.
    - Widen power switch opening
    Deleted Cura project, as I was having trouble with stale models.
    [bottom_enclosure.stl, button.stl, cura_project.3mf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]
2020-02-02 Add a front panel decal
    A bit cheesy right now, a placeholder for something hopefully a bit nicer.
    There is a small 0.4mm inset on the front panel to protect the edges of the
    decal from peeling.
    [enclosure.scad]
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2020-02-02 The width of the top and bottom of enclosure surfaces were wrong.
    I was making this more complicated than it needed to be.
    [bottom_enclosure.stl, enclosure.scad, top_enclosure.stl]
2020-02-03 A few enclosure fixes based on 2nd test print
    - Position of buttons on decal was offset
    - Make the top of the buttons rounded.
    - The base of the buttons needs a smaller radius, otherwise they interfere.
    - Increase size of overlap lip.
    - Increase length of top bosses
    [bottom_enclosure.stl, button.stl, enclosure.scad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]
2020-02-03 A few more enclosure improvements
    - The bottom bosses were not actually connected to the enclosure
    - Attach the bottom bosses to the side walls to strengthen them
    [bottom_enclosure.stl, button.stl, enclosure.scad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]
2020-02-03 Clean up icons on decal
    Also make the lower bosses extend to the bottom of the shell. This shouldn't have any
    change in the final model.
    [enclosure.scad]
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2020-02-03 Fix a few Digikey links
    [BOM.csv]
2020-02-03 Make counterbore holes deeper
    I had made the upper bosses a bit longer, but hadn't adjusted the
    counterbores. The result is that the screws wouldn't engage as
    deeply. Change so the counterbore depth is relative to the bottom
    of the boss instead of the case height.
    Also tweaked some dimensions to make sure the screw head has enough plastic
    to hold onto, but these may be below the abilities of the printer anyway.
    [enclosure.scad]
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2020-02-04 Hollow out the inside of buttons and add cross supports.
    I'm switching to 100% infill. In most places, infill is unnecessary anyway, because the
    enclosure walls are thin. It ended up being detrimental in some places it was used, as I
    thickened them to add strength around bosses. The buttons were an exception to both of
    these cases.
    [enclosure.scad]
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2020-02-05 Outside case radius was wrong.
    I was using the boss radius without accounting for distance between it and the outside.
    With the larger radius, I needed to decrease the chamfer width, otherwise it was excessive.
    Also thickened walls to 2mm. The lip broke off in the previous print.
    Removed blocks supporting bosses. There was a lot of warping near these.
    [enclosure.scad]
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2020-02-05 Fix USB and power switch cutouts.
    [bottom_enclosure.stl, enclosure.scad, top_enclosure.stl]
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2020-02-05 Fix boss lengths so they match up with the PCB position.
    [bottom_enclosure.stl, button.stl, enclosure.scad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]
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2020-02-08 Switch to a microcontroller with more SRAM
    This is necessary to enable some effects like reverb and echo.
    This part has a similar pinout, but not exactly the same, which required some layout
    changes.
    I also took this opportuntity to move the serial pins to a separate header with its
    own ground, which makes connecting a serial debugger and SWD interface at the same
    time easier.
    [BOM.csv, audio.sch, logic_board.kicad_pcb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]
2020-02-08 Increase Z height of enclosure by 1.5mm to make more room for battery.
    [bottom_enclosure.stl, enclosure.scad, top_enclosure.stl]
2020-02-08 Fix a few incorrect MCU pin connections from last change.
    [audio.sch, logic_board.kicad_pcb, mcu.sch]
2020-02-08 Fix button icon positioning after previous cutout fix.
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2020-02-09 Power layout improvements
    Route the output from the power supply inductor past two output caps before connecting to
    power plane with a via. Previously it went directly into the power, and the two caps connected
    directly to power. This should help reduce ripple and noise injected into the power plane.
    This required rerouting USB data lines under the inductor, which is probably not great for
    signal integrity.
    [logic_board.kicad_pcb]
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2020-02-09 Add pulldown resistors on CC1 and CC2 pins to enable VBUS power
    [BOM.csv, logic_board.kicad_pcb, power.sch]
2020-02-09 Remove USB series termination resistors
    Page 179 of the datasheet states: "No external termination series
    resistors are required on USB_PD P(D+) and USB_DM (D-); the matching
    impedance is already included in the embedded driver." (There's a typo,
    presumably they meant USB_DP).
    [BOM.csv, logic_board.kicad_pcb, power.sch]
2020-02-09 Connect VBAT to VDD
    From AN5096, "If no external battery is used in the application, it is recommended
    to connect VBAT externally to VDD."
    [logic_board.kicad_pcb, mcu.sch, power.sch]
2020-02-09 Swap MCU resonator so the input/outputs are connected correctly.
    [logic_board.kicad_pcb, mcu.sch]
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2020-02-09 Move I2C2_SDA from PA8 to PA10
    There is conflicting information in the datahsheet. Table 13 says this
    should be PA10, but Table 12 says PA8. I'm using the former, as it
    has actual mappings. This would be fairly easy to rework with a blue
    wire if I guessed wrong: jumpering the pins together and making PA10
    be an input.
    [logic_board.kicad_pcb, mcu.sch]
2020-02-09 Switch from switching to LDO regulator
    This simplifies the design and reduces part count. Since the typical
    use case is only a few hours of usage, the difference in efficiency
    doesn't seem to justify the additional complexity.
    [BOM.csv, logic_board.kicad_pcb, mcu.sch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]
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2020-02-09 Adjust DRC rules
    Change minimum trace clearance to 0.127mm (5 mil), which is specified by OSHPark. This silences
    a bunch of DRC warnings around the charger IC footprint.
    [logic_board.kicad_pcb]
2020-02-09 Move vias off pads
    Having a via on a pad can complicate soldering because the vias wick away
    solder.
    [logic_board.kicad_pcb]
2020-02-09 A little more board cleanup
    Move some vias off pads that I missed in the last change.
    Clean up silk screened references.
    [logic_board.kicad_pcb]
2020-02-09 Move a bunch of bypass caps to the top of the board.
    There is a lot of lore around bypass caps. I suspect it probably
    doesn't matter much, but this is the more conservative approach.
    [logic_board.kicad_pcb]
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2020-02-10 Minor schematic cleanups: fix label directions, overlapping values/references.
    [audio.sch, logic_board.sch, mcu.sch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]
2020-02-10 Enable clocks to GPIO block in blinking program.
    I won't be able to test this until I get the boards back and assemble them, so this
    is speculative based on datasheets for now.
    [main.c]
2020-02-10 Consolidate UART and SWD headers into a single one, which takes up less space.
    [logic_board.kicad_pcb, mcu.sch]
2020-02-10 Leave a small via connected to pin PA8.
    There is a contradiction in the datasheet between two tables. I've taken an educated guess,
    but if that is wrong, this will make it easier to rework.
    [logic_board.kicad_pcb]
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2020-02-14 Use longer screws
    The M2x6 screws are too short with the PCB in place. This requires upgrading to M2.3 screws.
    Increased bore sizes. I had to make the top bosses tapered to accomodate the larger counterbore.
    I tapered the bottom ones just to match.
    Also increased the RELIEF to 0.8, as the parts do warp a bit and things stick during assembly.
    [bottom_enclosure.stl, enclosure.scad, logic_board.kicad_pcb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]
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2020-02-18 Adjust enclosure a bit
    - For lip/groove at seam, I had previously subtracted the relief from only
    the bottom. Change so it is divided between the top and bottom so one isn't thinner/weaker than the other.
    - I was previously subtracting the relief from the diameter of the button holes.
    Instead, subtract twice the relief (or subtract the relief from the radius), so the relief ends up being the clearance all the way around the hole.
    - Add a separate constant for the PCB inset from the inside wall, as it is quite a bit largerthan the relief.
    - With all of these changes, crank the relief down to 0.5.
    - Subtract the relief from the height of the bottom lip so it can fit snug.
    Also cleaned up by c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
    [enclosure.scad]
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2020-02-18 Connect the thermal pad of the charger per datasheet recommendations
    - Added a separate pin 11 for the thermal pad in the custom symbol.
    - Ground the thermal pad.
    - Add a bunch of vias to conduct heat through the board.
    - Add a copper pour on the back side of the board to radiate heat.
    Although the backside pour is at ground potential, I have added keepouts
    around all ground via in its area to avoid ground loops.
    [logic_board.kicad_pcb, power.sch]
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2020-02-19 Update to symbols from newest KiCad
    LEDs were also on the wrong side of the board.
    [audio.sch, logic_board.kicad_pcb, mcu.sch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]
2020-03-05 Fix I2C2_SDA, which was mislabeled in the STM32G473 datasheet.
    It now connects to pin30. In the G474 datasheet, both places
    that reference this pin agree.
    [logic_board.kicad_pcb, mcu.sch]
2020-03-10 The custom footprint for the tactile had the pins misnumbered
    They were rotated 90 degrees. There are actually four pins, with
    two on each side connected internally. There doesn't seem to be
    an easy way to indicate that in kicad, so only two are connected
    to the schematic symbol.
    [logic_board.kicad_pcb]
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
